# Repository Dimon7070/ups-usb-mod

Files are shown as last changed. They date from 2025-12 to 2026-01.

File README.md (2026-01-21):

### Modification in progress
Plans:
- [x] Added Gerber and BOM for original schematic
- [x] Added schematic, Gerber and BOM for 0402 smd parts and ADUM1201 isolator
- [ ] add scematics with SMD sizes that are more hand-soldering friendly.
- [ ] add gerber files 
- [ ] add wiki with explanation about USB-Serial IC setup

# original README
# ups-usb
This repo contains the isolated USB to serial board that I designed for a Serioux LD600LI UPS to get it to talk reliably with NUT.
Project was designed using Kicad V8.  For more information check out [Voltlog #503](https://youtu.be/ZeoCBQmW2Rw)
Image of the assembled PCB

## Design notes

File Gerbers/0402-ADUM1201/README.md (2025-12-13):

0402-ADUM1201 gerbers and placement files

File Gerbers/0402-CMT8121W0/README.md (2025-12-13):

0402-CMT8121W0 gerbers and placement files

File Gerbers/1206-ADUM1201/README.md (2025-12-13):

1206-ADUM1201 gerbers and placement files

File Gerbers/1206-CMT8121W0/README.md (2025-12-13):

1206-CMT8121W0 gerbers and placement files

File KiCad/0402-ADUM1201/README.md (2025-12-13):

Schematics with 0402 smd components and ADUM1201 isolator

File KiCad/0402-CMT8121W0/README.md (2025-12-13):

Original schematics with 0402 smd components and CMT8121W0 isolator

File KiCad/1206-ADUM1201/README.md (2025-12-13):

Schematics with 1206 smd components and ADUM1201 isolator

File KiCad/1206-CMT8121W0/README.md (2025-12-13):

Schematics with 1206 smd components and CMT8121W0 isolator

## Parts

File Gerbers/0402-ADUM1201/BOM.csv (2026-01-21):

Reference | Value | Datasheet | Footprint | Qty | DNP | LCSC
C1,C4,C7 | 4.7uF | ~ | Capacitor_SMD:C_0402_1005Metric | 3 |  | C23733
C2,C3,C5,C6 | 0.1uF | ~ | Capacitor_SMD:C_0402_1005Metric | 4 |  | C307331
D1 | TX | https://datasheet.lcsc.com/lcsc/2008201032_Foshan-NationStar-Optoelectronics-NCD0603G1_C84267.pdf | LED_SMD:LED_0402_1005Metric | 1 | DNP | C130723
D2 | RX |  | LED_SMD:LED_0402_1005Metric | 1 | DNP | C130719
J1 | UPS | ~ | Connector_JST:JST_XH_B4B-XH-A_1x04_P2.50mm_Vertical | 1 |  | C19271370
J2 | USB Type-B | https://jlcpcb.com/api/file/downloadByFileSystemAccessId/8588892898368622592 | Connector_USB:USB_B_Lumberg_2411_02_Horizontal | 1 |  | C720549
R1 | 22.1K | ~ | Resistor_SMD:R_0402_1005Metric | 1 |  | C43473
R2 | 47.5K | ~ | Resistor_SMD:R_0402_1005Metric | 1 |  | C25896
R3 | 1K | ~ | Resistor_SMD:R_0402_1005Metric | 1 |  | C11702
R4,R5 | 1K | ~ | Resistor_SMD:R_0402_1005Metric | 2 | DNP | C11702
U1 | ADUM1201AR | https://www.analog.com/media/en/technical-documentation/data-sheets/ADuM1200_1201.pdf | Package_SO:SOIC-8_3.9x4.9mm_P1.27mm | 1 |  | C9669
U2 | USBLC6-2P6 | https://www.st.com/resource/en/datasheet/usblc6-2.pdf | Package_TO_SOT_SMD:SOT-666 | 1 |  | C2827693
U3 | CP2102N-A01-GQFN28 | https://www.silabs.com/documents/public/data-sheets/cp2102n-datasheet.pdf | Package_DFN_QFN:QFN-28-1EP_5x5mm_P0.5mm_EP3.35x3.35mm | 1 |  | C1550553

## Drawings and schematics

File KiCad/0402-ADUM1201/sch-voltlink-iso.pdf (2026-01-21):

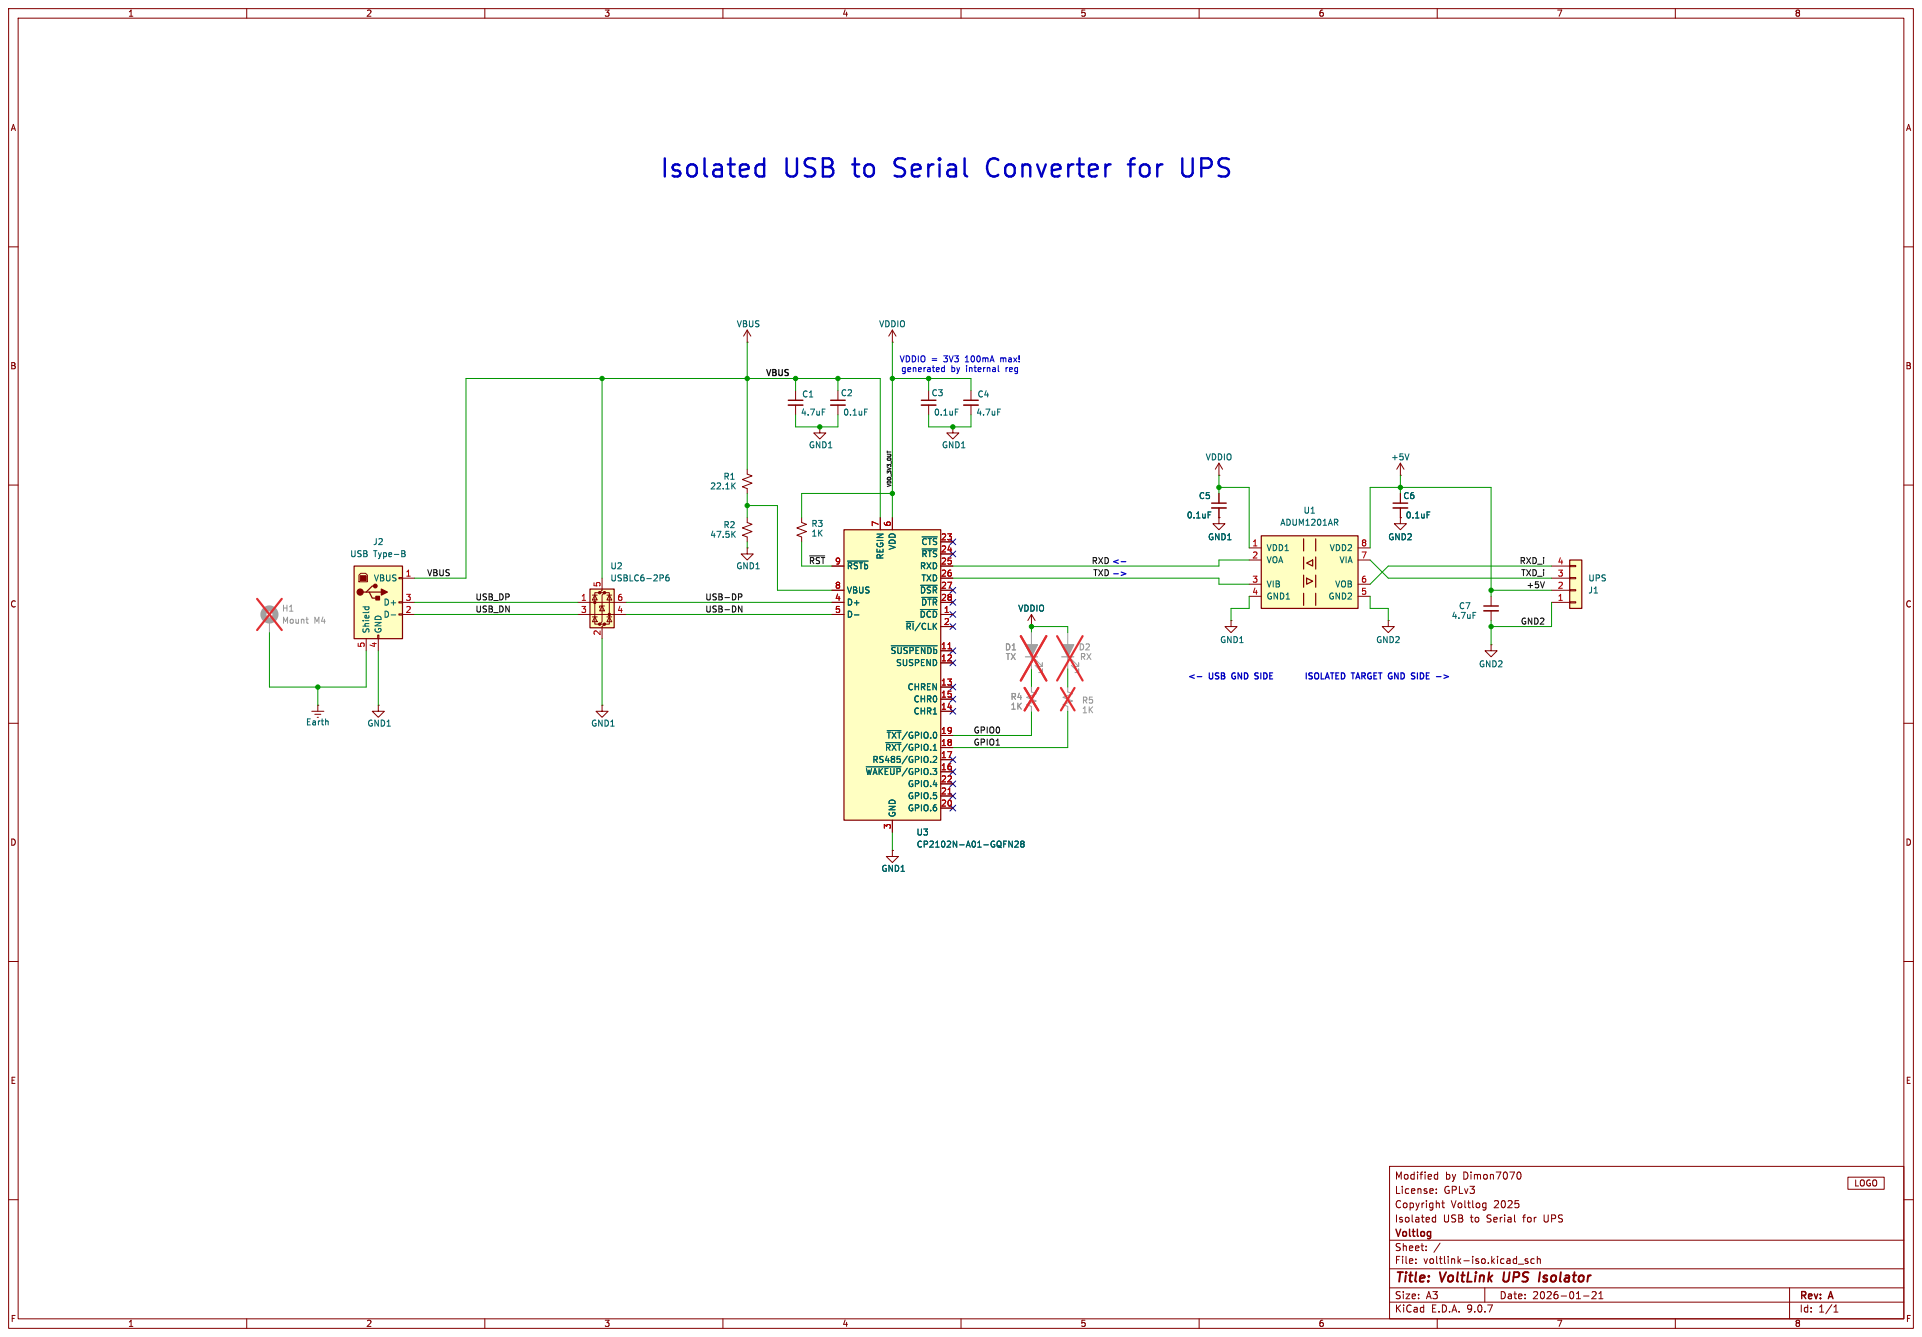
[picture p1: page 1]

-> Isolated USB to Serial Converter for UPS

3 ~{CTS} 23 ~{RTS} 24 RXD 25 TXD 26 ~{DSR} 27 ~{DTR} 28 ~{DCD}1 ~{RI}/CLK2 ~{SUSPENDb}11 SUSPEND 12 CHREN 13 CHR0 15 CHR1 14 ~{TXT}/GPIO.019 ~{RXT}/GPIO.118 RS485/GPIO.2 17 ~{WAKEUP}/GPIO.316 GPIO.4 22 GPIO.5 21 GPIO.6 20 U3 CP2102N-A01-GQFN28 USB-DP

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

ISOLATED TARGET GND SIDE ->

Id: 1/1 Title: VoltLink UPS Isolator File: voltlink-iso.kicad_sch Sheet: / Voltlog

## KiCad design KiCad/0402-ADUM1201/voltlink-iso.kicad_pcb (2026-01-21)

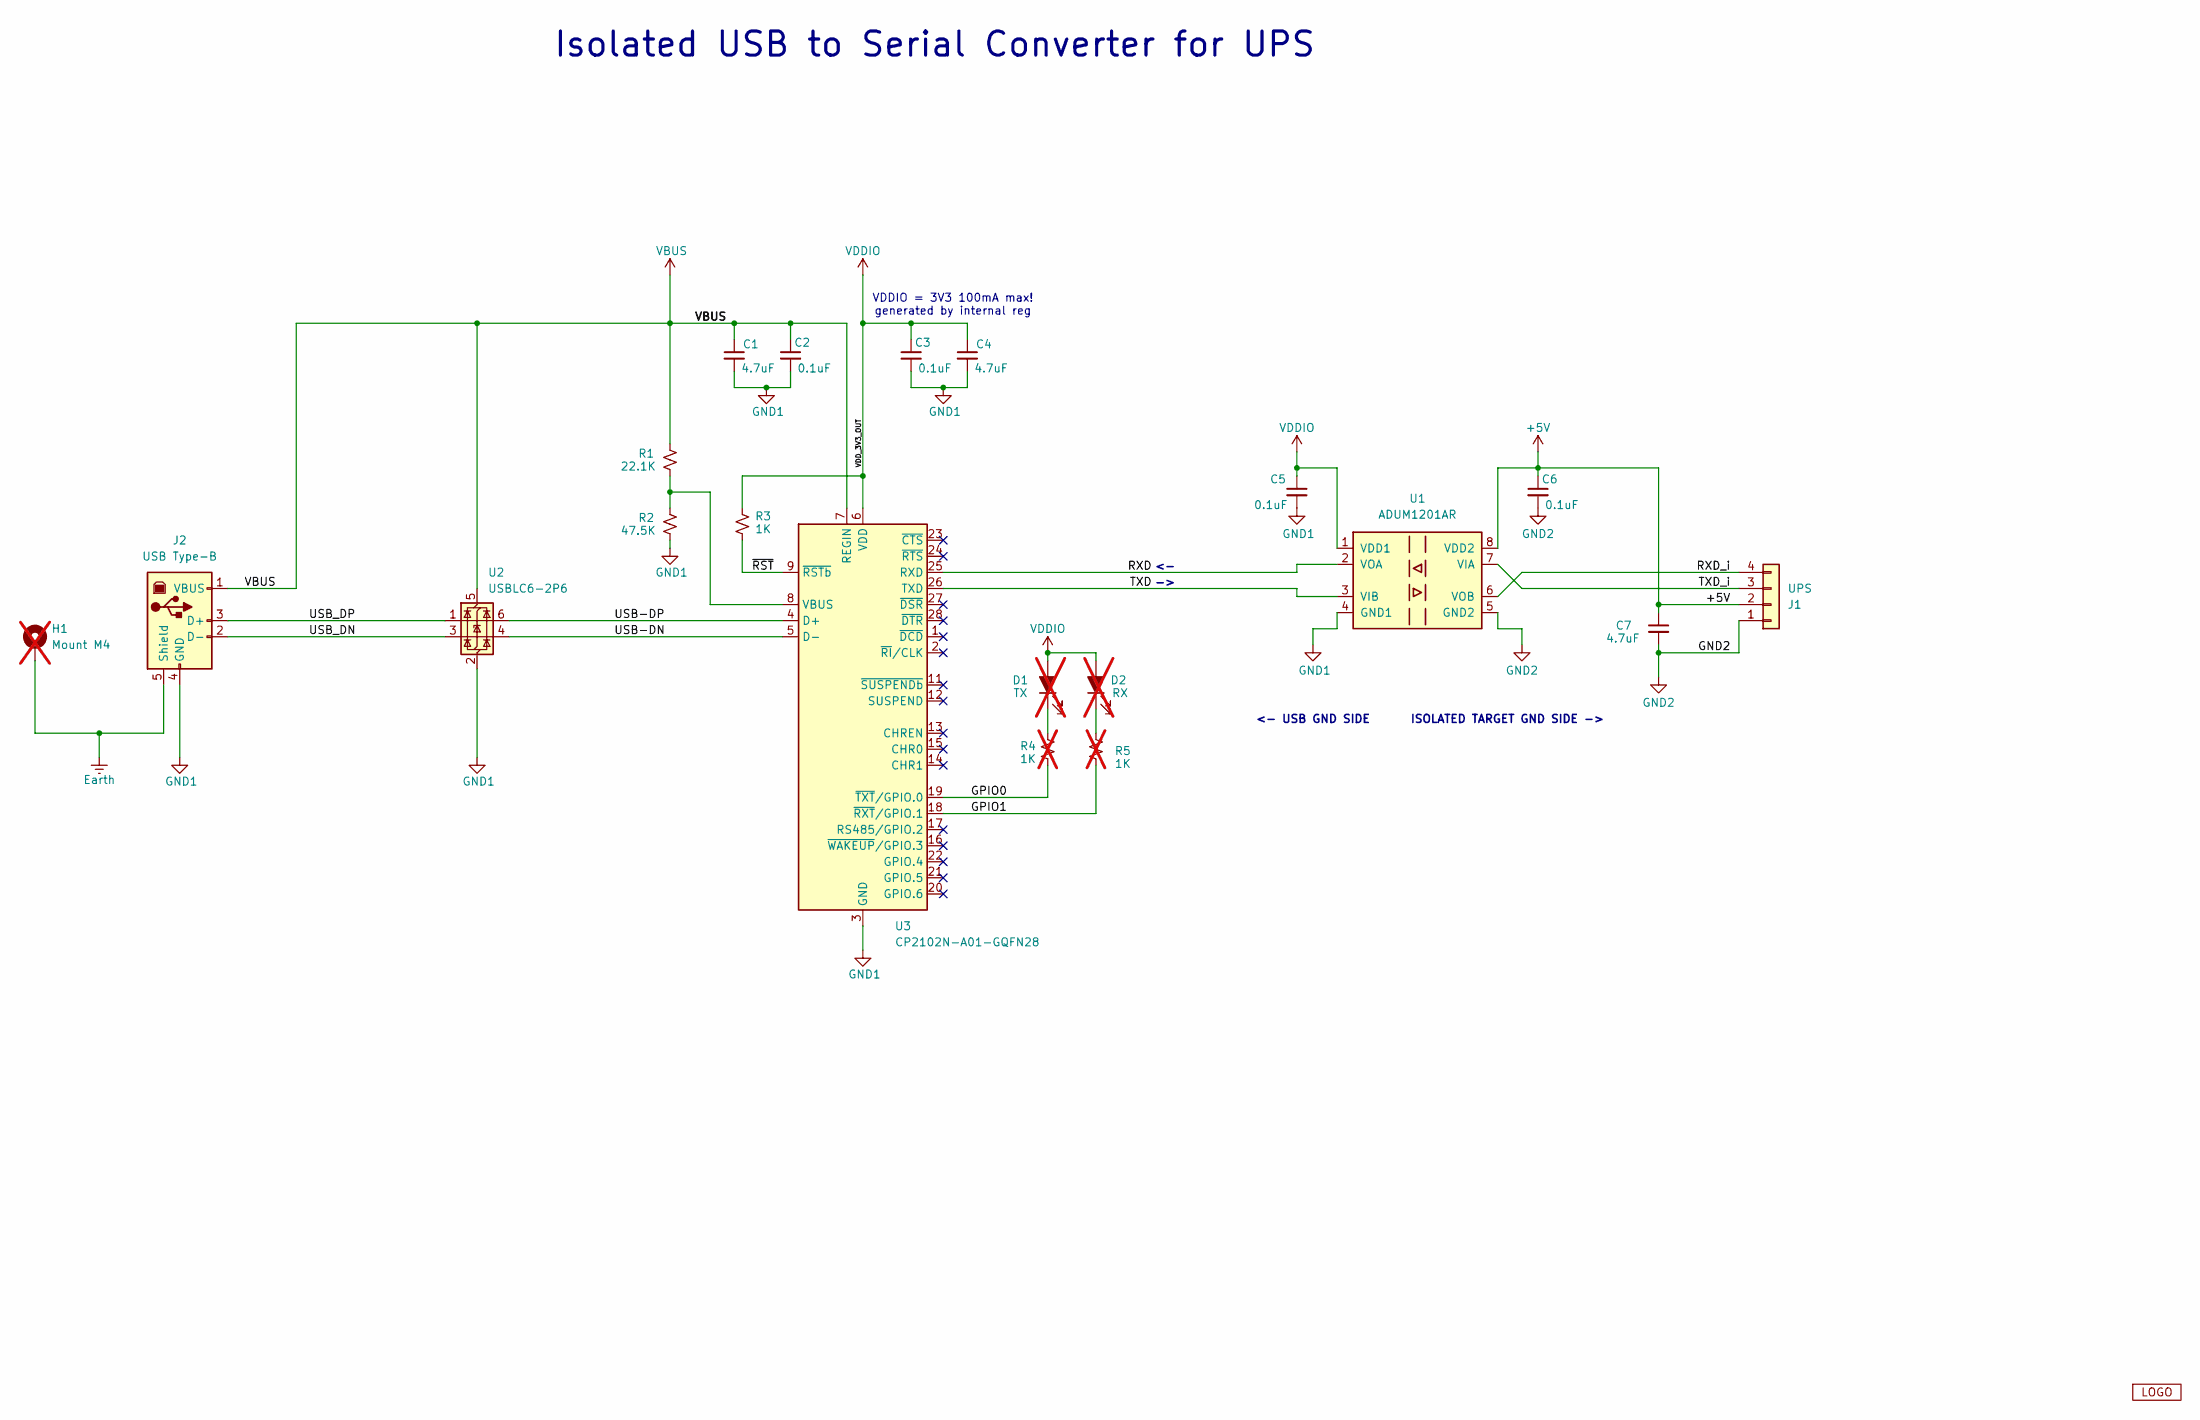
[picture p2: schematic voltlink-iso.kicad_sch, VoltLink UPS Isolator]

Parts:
C1, C4, C7: 4.7uF; C_0402_1005Metric; Voltage 10V; LCSC C23733
C2, C3, C5, C6: 0.1uF; C_0402_1005Metric; Voltage 50V; LCSC C307331
D1: TX; LED_0402_1005Metric; LCSC C130723; not fitted
D2: RX; LED_0402_1005Metric; LCSC C130719; not fitted
H1: Mount M4; M4_TH_terminal; not fitted
J1: UPS; JST_XH_B4B-XH-A_1x04_P2.50mm_Vertical; LCSC C19271370
J2: USB Type-B; USB_B_Lumberg_2411_02_Horizontal; LCSC C720549
R1: 22.1K; R_0402_1005Metric; LCSC C43473
R2: 47.5K; R_0402_1005Metric; LCSC C25896
R3: 1K; R_0402_1005Metric; LCSC C11702
R4, R5: 1K; R_0402_1005Metric; LCSC C11702; not fitted
U1: ADUM1201AR; SOIC-8_3.9x4.9mm_P1.27mm; LCSC C9669
U2: USBLC6-2P6; SOT-666; LCSC C2827693
U3: CP2102N-A01-GQFN28; QFN-28-1EP_5x5mm_P0.5mm_EP3.35x3.35mm; LCSC C1550553
V1: VOLTLOG_LOGO; voltlog_silk_5mm

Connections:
+5V: C6.1, C7.1, J1.2, U1.8 (VDD2)
/GPIO0: R4.1, U3.19 (~TXT/GPIO.0)
/GPIO1: R5.1, U3.18 (~RXT/GPIO.1)
/RXD: U1.2 (VOA), U3.25 (RXD)
/RXD_i: J1.4, U1.6 (VOB)
/TXD: U1.3 (VIB), U3.26 (TXD)
/TXD_i: J1.3, U1.7 (VIA)
/USB-DN: U2.4 (I/O2), U3.5 (D-)
/USB-DP: U2.6 (I/O1), U3.4 (D+)
/USB_DN: J2.2 (D-), U2.3 (I/O2)
/USB_DP: J2.3 (D+), U2.1 (I/O1)
/~RST: R3.1, U3.9 (~RSTb)
Earth: H1.1, J2.5 (Shield)
GND1: C1.2, C2.2, C3.2, C4.2, C5.2, J2.4 (GND), R2.2, U1.4 (GND1), U2.2 (GND), U3.3 (GND), U3.29 (GND)
GND2: C6.2, C7.2, J1.1, U1.5 (GND2)
unnamed: D1.1 (K), R4.2
unnamed: D2.1 (K), R5.2
unnamed: R1.2, R2.1, U3.8 (VBUS)
VBUS: C1.1, C2.1, J2.1 (VBUS), R1.1, U2.5 (VBUS), U3.7 (REGIN)
VDDIO: C3.1, C4.1, C5.1, D1.2 (A), D2.2 (A), R3.2, U1.1 (VDD1), U3.6 (VDD)

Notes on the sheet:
Isolated USB to Serial Converter for UPS
<- USB GND SIDE
ISOLATED TARGET GND SIDE ->
VDDIO = 3V3 100mA max! generated by internal reg

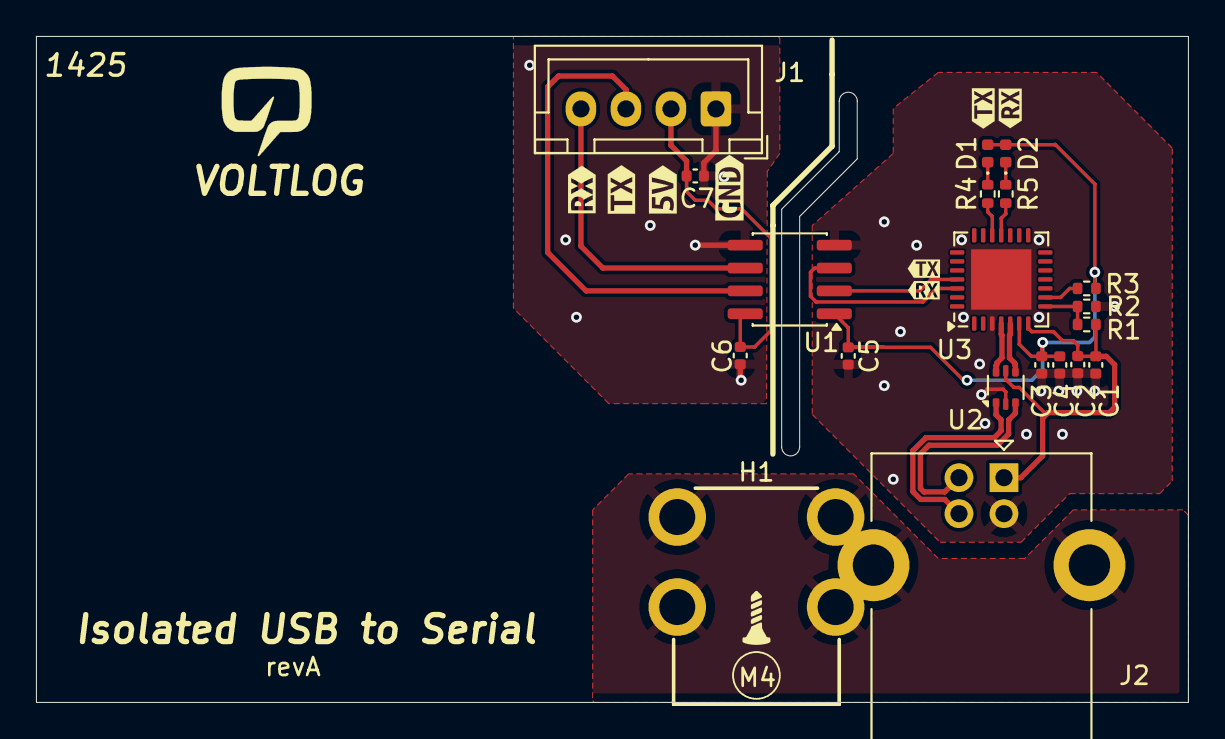
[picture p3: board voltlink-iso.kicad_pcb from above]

Board: 2 copper layers, 64.0 x 37.0 mm, 29 parts (0 on the bottom side), 20 nets.

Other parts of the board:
kibuzzard-67EF7DAE: G***; kibuzzard-67EF7DAE
kibuzzard-67EF7DB2: G***; kibuzzard-67EF7DB2
kibuzzard-67EF87AE: G***; kibuzzard-67EF87AE
kibuzzard-67EF88A2: G***; kibuzzard-67EF88A2
kibuzzard-67EF879C: G***; kibuzzard-67EF879C
kibuzzard-67EF8788: G***; kibuzzard-67EF8788
kibuzzard-67EF8792: G***; kibuzzard-67EF8792
kibuzzard-67EF8898: G***; kibuzzard-67EF8898

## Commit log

2025-12-13 Folder structure and simple description for KiCad projects
2025-12-13 Moved original schematicd to corresponding folder
    [voltlink-iso.kicad_pcb, voltlink-iso.kicad_sch]
2025-12-13 Remove files from old location
    [voltlink-iso.kicad_pcb, voltlink-iso.kicad_sch]
2025-12-13 Gerber folder
2025-12-13 added gerbers
2026-01-20 added BOM file
2026-01-21 Added ADUM1201 schematic variant
    [voltlink-iso.kicad_pcb, voltlink-iso.kicad_sch]
2026-01-21 Modified ADUM1201 schematic, added BOM and Gerbers
    [BOM.csv, voltlink-iso.kicad_pcb]

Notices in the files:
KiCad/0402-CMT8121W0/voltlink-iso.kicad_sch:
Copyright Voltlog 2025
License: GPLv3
